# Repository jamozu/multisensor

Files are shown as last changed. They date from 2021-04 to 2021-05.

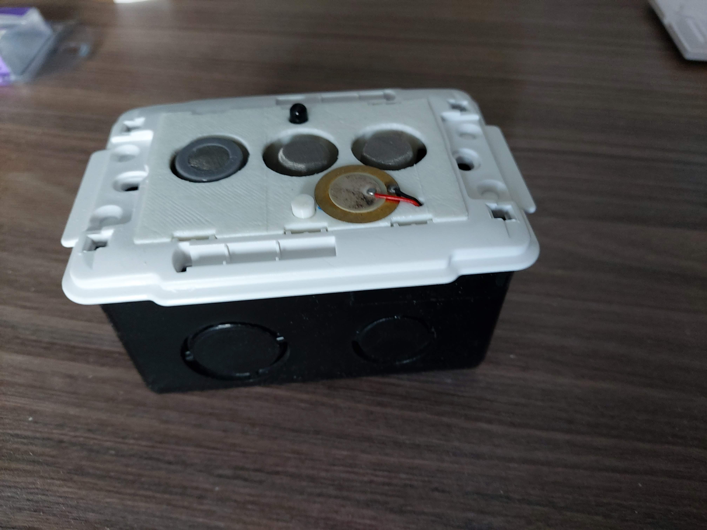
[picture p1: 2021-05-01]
pics/Pic_AQS_Assembled.jpg

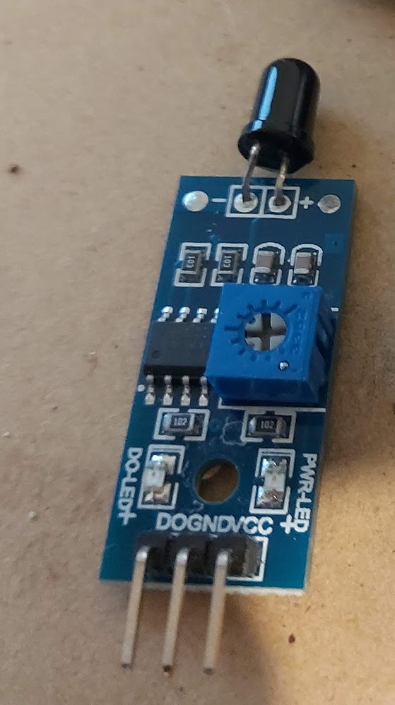
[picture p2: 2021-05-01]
pics/Pic_AQS_Flame.jpg

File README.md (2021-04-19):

# Multi-Sensor
This project consists of a module that manages different sensors for home use. The idea is to be able to mix and match different sensors, according to the requirements of each area of the house, using a single PCB design and a configurable sketch, making it easier to setup and maintain a sensor network.

The sensor module is based on the MySensors library using an Arduino® Mini Pro, which has a good number of interface pins, it has a small footprint and is suited for running on batteries, with the NRF24L01 radio module for wireless communication.

For a full description check the Doc Multi_Sensor.pdf (https://github.com/jamozu/multisensor/blob/main/Multi_Sensor.pdf).

Details on the PCB: https://oshwlab.com/jamozu/multi_project_copy_copy_copy_copy_copy_copy

# License
This project is licensed under the CERN-OHL-P v2

# Special Thanks to
MySensors Team, by creating a great and inspiring platform for all DIYers and IoT enthusiasts. (http://www.mysensors.org)
Damian and Gnd_To_Vcc, for their tips on using PIR sensors with 3.3 V (https://screenzone.eu/modify-hc-sr501-pir-sensor-to-work-with-3-3v/), (https://gndtovcc.home.blog/2020/04/23/modifying-cheap-pir-motion-sensor-to-work-at-3-3v/)
system, for an excellent template for writing values to EEPROM (https://forum.arduino.cc/t/writing-float-values-to-eeprom/41607/3)
hek, who has a very complete example of the use of air quality sensors. (https://www.mysensors.org/build/gas)
To all the DIYers out there who are enriching these IoT development platforms, making it easier for new enthusiasts.

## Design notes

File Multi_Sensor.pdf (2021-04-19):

## MULTI-SENSOR

This project consists of a module that manages different sensors for home use. The idea is to be able to mix and match different sensors, according to the requirements of each area of the house, using a single PCB design and a configurable sketch, making it easier to setup and maintain a sensor network.

## Description

The sensor module is based on the MySensors library using an Arduino® Mini Pro, which has a good number of interface pins, it has a small footprint and is suited for running on batteries.
The radio module for wireless communication is the NRF24L01.
It supports the following sensors:
- Motion Sensor.
- 1 – 3 Door / Window sensors.
- Temperature and humidity sensor.
- Flame sensor.
- Light sensor.
- LUX Sensor (I2C).
- Smoke sensor.
- Gas sensor.
- CO sensor.
- 1 – 3 Moisture sensors.
- 1 – 3 Leak detectors.

It also includes the features:
- Battery operation or battery backup
- Audible Alarm
- Reset / Test / Calibrate button

## Hardware

The module is based on the Arduino® Mini Pro and the NRF24L01 radio, using readily available sensor boards, connected through a PCB.
The sensor module can be powered using a small power supply, through batteries, or a combination of a power supply and rechargeable battery for backup.

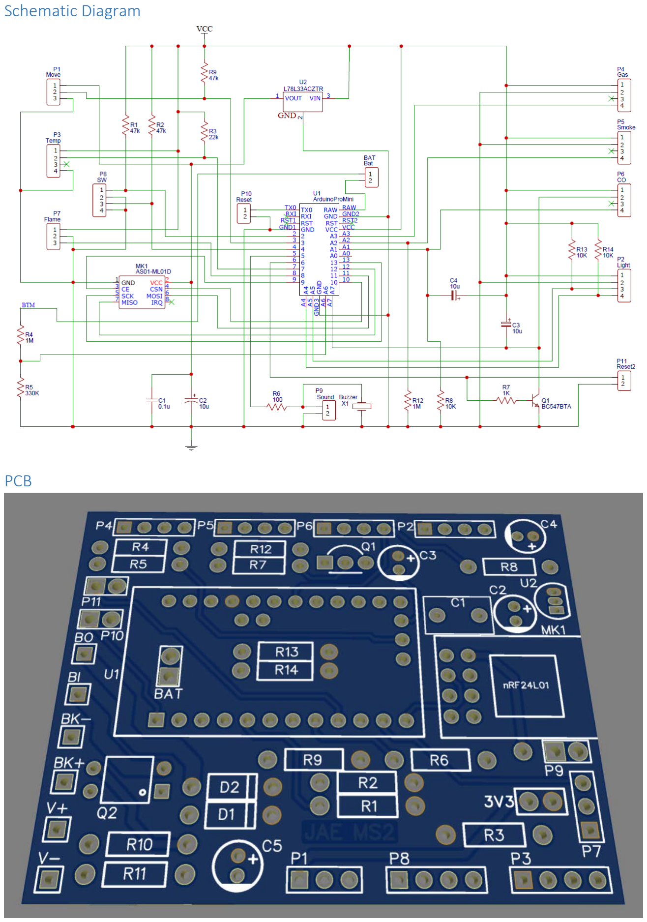
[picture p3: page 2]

Schematic Diagram

PCB

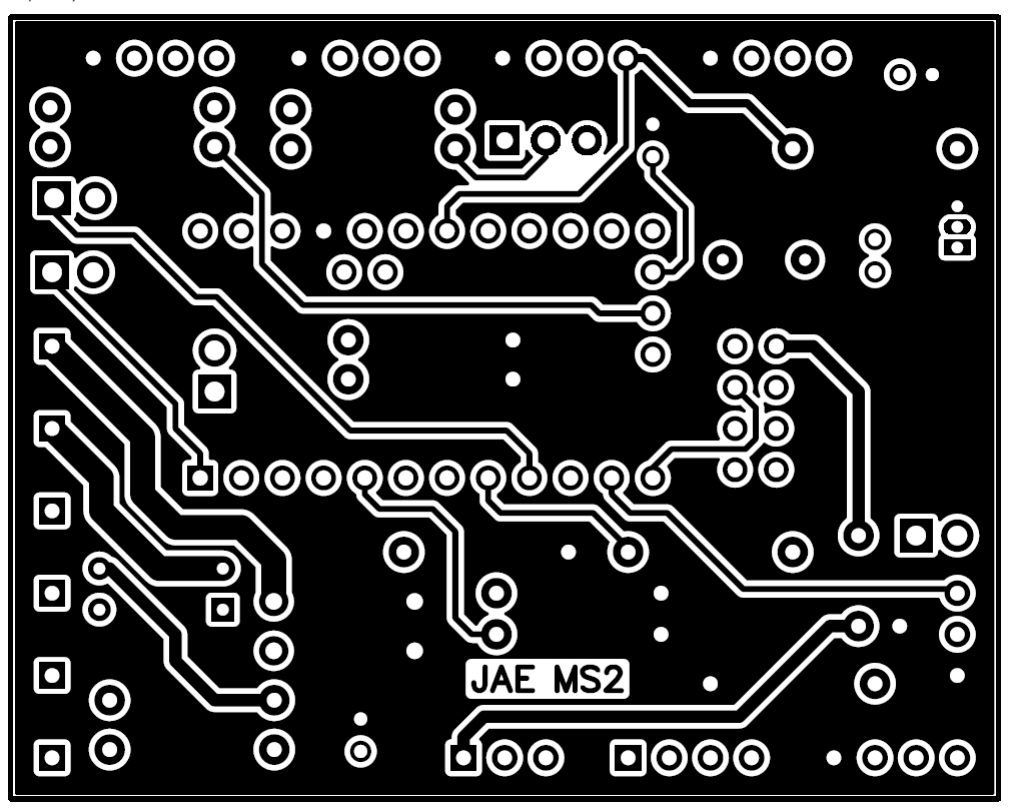
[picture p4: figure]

Top Layer

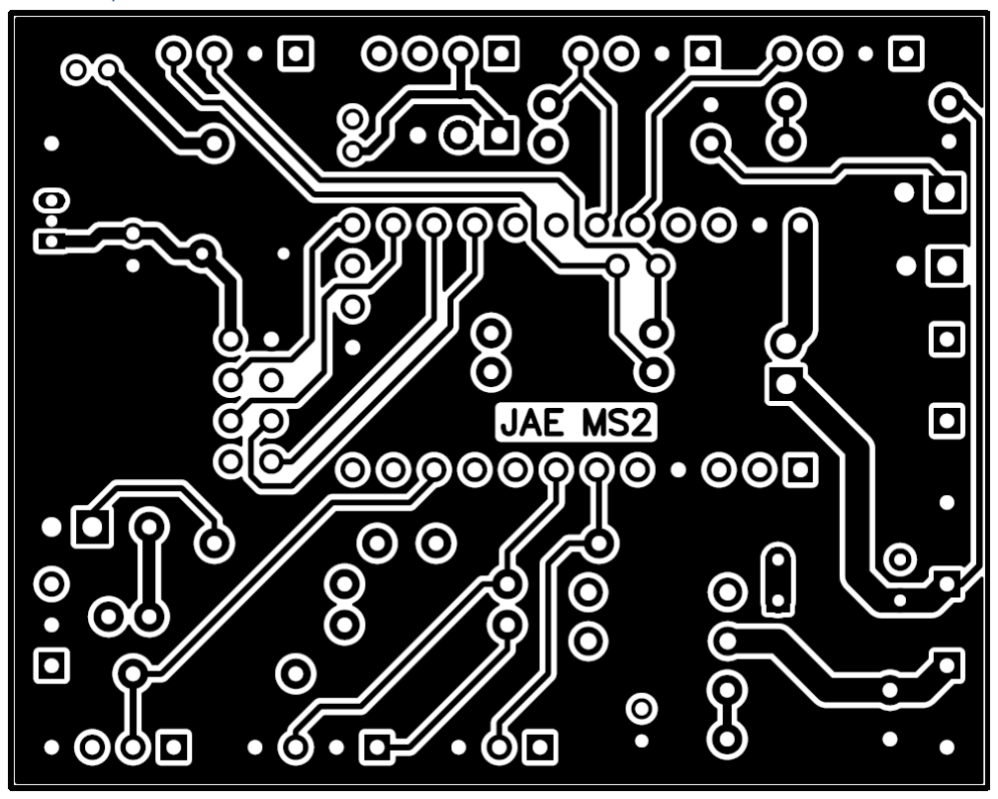
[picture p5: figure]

Bottom Layer

Component Silk Mask

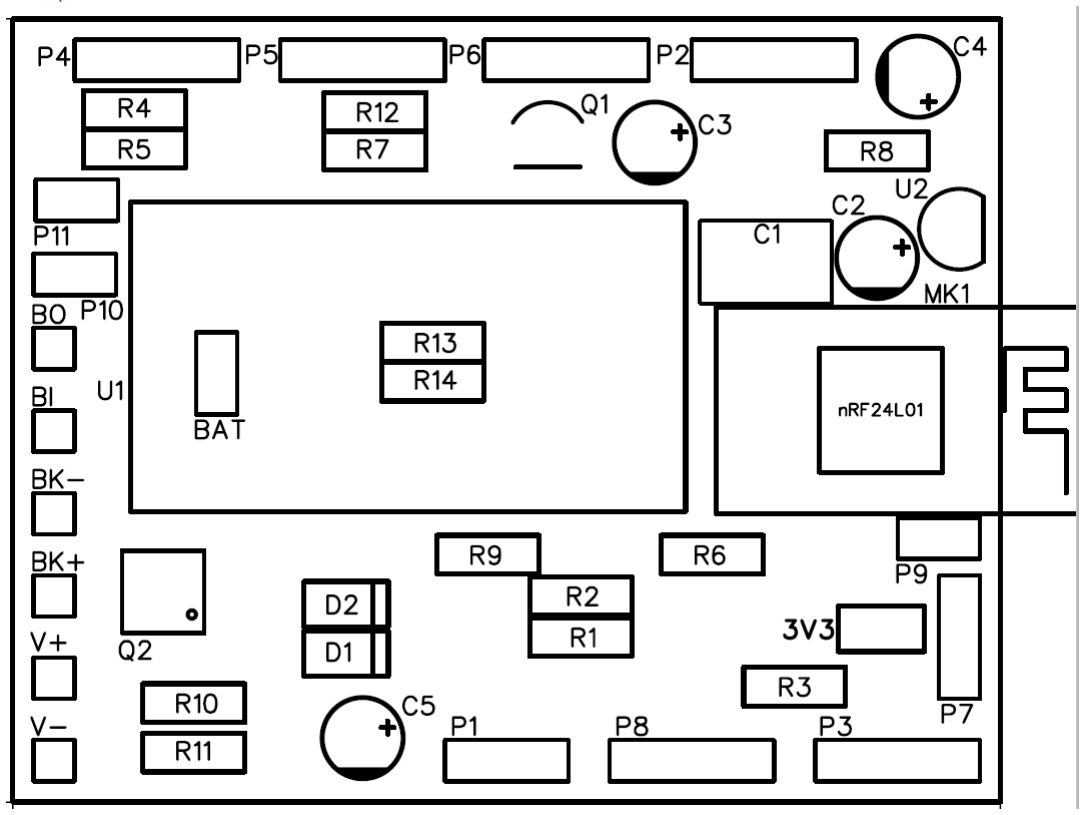
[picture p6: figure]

Microcontroller
The module can be configured with a 5V or 3.3V Arduino Pro Mini microcontroller module.
In the case of battery operation, it is recommended to use the 3.3V microcontroller. In this case, all sensors must be rated to operate at 3.3V.
In the case of a 5V microcontroller you can use 5V and 3.3V sensors in combination.
The NRF24L01 radio module requires 3.3V, so a regulator (U2) for the radio (and the motion sensor) is included in the circuit, in case of using a 5V microcontroller.
If the controller is 3.3V, the U2 regulator is not required, but it is necessary to put a jumper between terminals 1 and 3 of U2.

Sensors
Some of the sensors use the same pins in the microcontroller, so a combination of sensors can be chosen according to the following table:
Arduino Pins | Sensors | Features | Sleep
1 | | | | Button | N/A
2 | Door 1 | | | Button
3 | Door 2 | PIR Motion | | Button

4 | Door 3 | Optional
5 | | | | Alarm
7 | Temp. / Hum.
8 | Flame
6, A1, A7 | MQ-7 | Moist 3 | Leak 3 | Button | Optional
A2 | MQ-2 | Moist 2 | Leak 2
A3 | MQ-5 | Moist 1
A4, A5 | Light | Lux
A6 | | | | Battery monitor

The sensors that require it, have been configured with external Pull Up resistors to improve energy consumption and to be able to operate with batteries.
Sensor | VCC | Reference
PIR Motion Sensor | 3.3V, 5V | https://www.adafruit.com/product/189
Door Sensor | 3.3V, 5V | https://www.sparkfun.com/products/8642
| 3.3V, 5V | https://www.sparkfun.com/products/13247
| 3.3V, 5V | https://www.sparkfun.com/products/13014
Temp / Humidity sensor | 3.3V, 5V | https://learn.adafruit.com/dht
Light Sensor | 5V | https://www.makerfabs.com/light-sensor-module.html
| 3.3V, 5V | https://www.adafruit.com/product/2748
| 3.3V, 5V | http://arduinolearning.com/code/arduino-lx1972-light-sensor-example.php (http://arduinolearning.com/code/arduino-lx1972-light-sensor-example.php)
LUX Sensor | 3.3V, 5V | https://www.adafruit.com/product/4162
| 3.3V, 5V | https://www.adafruit.com/product/439
| 3.3V, 5V | https://www.adafruit.com/product/4681
Flame Sensor | 3.3V, 5V | https://www.pcboard.ca/flame-sensor-module
Smoke Sensor | 5V | https://www.smart-prototyping.com/MQ2-gas-sensors-module.html (https://www.smart-prototyping.com/MQ2-gas-sensors-module.html)
Gas Sensor | 5V | https://www.smart-prototyping.com/MQ-5-Methane-Gas-Sensor-Module.html?search=mq-5 (https://www.smart-prototyping.com/MQ-5-Methane-Gas-Sensor-Module.html?search=mq-5)
CO Sensor | 5V | https://www.waveshare.com/mq-7-gas-sensor.htm
Moisture sensor | 3.3V, 5V | https://www.seeedstudio.com/Grove-Capacitive-Moisture-Sensor-Corrosion-Resistant.html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 (https://www.seeedstudio.com/Grove-Capacitive-Moisture-Sensor-Corrosion-Resistant.html)
| 3.3V, 5V | https://www.seeedstudio.com/Grove-Moisture-Sensor.html
Leak Sensor | 3.3V, 5V | https://www.aartech.ca/vip1000-h2o/flair-waterguard-water-detector-5-24vdc-white.html (https://www.aartech.ca/vip1000-h2o/flair-waterguard-water-detector-5-24vdc-white.html)

Wiring
a) Motion sensor

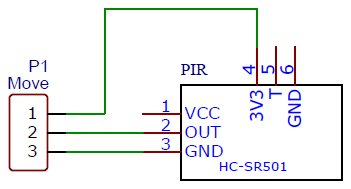
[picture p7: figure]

Install 47 KOhms resistor R9.
The motion sensor is connected to the 3.3V source, which is more efficient in power consumption. Consider the next articles for details on how to connect the PIR sensor: https://screenzone.eu/modify-hc-sr501-pir-sensor-to-work-with-3-3v/https://gndtovcc.home.blog/2020/04/23/modifying-cheap-pir-motion-sensor-to-work-at-3-3v/
b) Door sensors 1 and 3

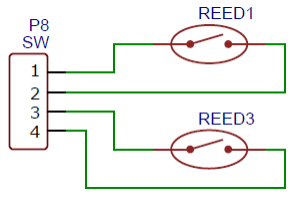
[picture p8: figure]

Install 47 KOhms resistors R1 (Door 1) and R2 (Door 2).

c) Door sensor 2

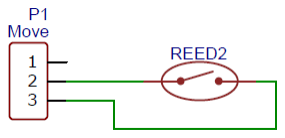
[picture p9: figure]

Install 47 KOhms resistor R9.

d) Temperature / Humidity sensor

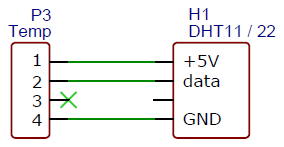
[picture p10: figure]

Install 22 KOhms resistor R3.

e) Light sensor

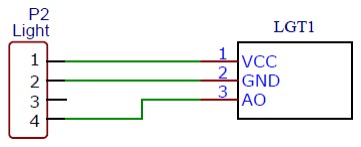
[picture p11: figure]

f) LUX Sensor
This sensor connects using two data pins with the I2C protocol. Any other I2C compatible sensor can be used instead or in parallel, but the sketch must be modified and the corresponding libraries installed.

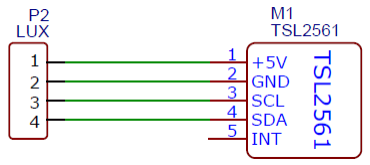
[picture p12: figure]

Install 10 KOhms resistors R13 and R14.

g) Flame sensor

Air Quality Sensors
The module supports 3 air quality sensors. MQ-2, MQ-5 and MQ-7. It is possible to replace the MQ-2 and MQ-5 with others similar sensors to detect specific gases, but the curves for the calculation of PPMs must be adjusted in the sketch. These MQ sensors have different sensitivities to different gases, however it is not possible to differentiate between one specific gas, for this reason the module has been equipped with a sensor for general air quality detection (MQ-2) and other more specific ones in order to have an accurate reading of the type of gas present, if required.
These sensors can consume up to 900mA, so it is not suitable for battery operation, so it is recommended to have a power supply with backup batteries, especially if using more than one sensor simultaneously.
For a simple, general use sensor and triggering an alarm, a single MQ-2 sensor is enough. If a more accurate reading of flammable gases is required, the MQ-5 can be used and MQ-7 can be used to detect Carbon Monoxide more accurately. The MQ-2 is a general-purpose sensor that can detect:
- Smoke
- Liquefied Petroleum Gas (LPG)
- Natural Gas (CH4)
- Carbon Monoxide (CO)
The MQ-5 is sensor focused on flammable gases and can detect:
- Liquefied Petroleum Gas (LPG)
- Natural Gas (CH4)
The MQ-7 sensor is specific for Carbon Monoxide. This sensor requires the application of two voltage levels alternately, so it requires constant operation of the microprocessor, so if this sensor is activated, the sleep mode is deactivated. The air quality sensors can be used to trigger an alarm or exclusively for monitoring.
When any of the air quality sensors is enabled in the module, the calibration button is automatically enabled. See below on the BUTTON and INTERRUPTIONS sections for more details.
If the alarm feature is enabled, it will be trigger if certain levels are reached in the monitored gases. The button is also used to reset / test the alarm.
h) Smoke sensor

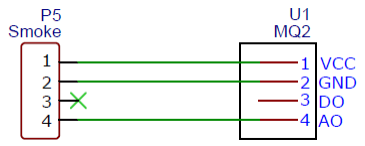
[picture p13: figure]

i) Gas sensor

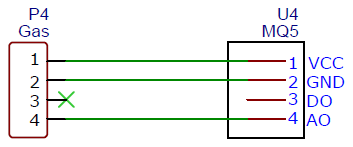
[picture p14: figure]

j) Carbon Monoxide sensor

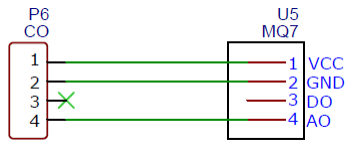
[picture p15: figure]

Install 1 KOhms resistor R7, 10 KOhms resistor R8, 10uF tantalum capacitors C3 and C4, and transistor Q1 (BC547B).

Moisture / Leak Sensors
Moisture sensors are used to measure humidity in media such as soil, but can also be used as water leak detectors, setting a humidity threshold.
The type of sensors supported are:
- https://www.seeedstudio.com/Grove-Capacitive-Moisture-Sensor-Corrosion-Resistant.html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 (https://www.seeedstudio.com/Grove-Capacitive-Moisture-Sensor-Corrosion-Resistant.html)
- https://www.seeedstudio.com/Grove-Moisture-Sensor.html
For the humidity in the soil it is recommended to use the capacitive type, since they are more durable and do not release harmful residues that can affect the chemistry of the soil.
There are other types of sensors that are used specifically to detect leaks:
- https://www.aartech.ca/vip1000-h2o/flair-waterguard-water-detector-5-24vdc-white.html
These sensors require a Pull Up resistor. The module supports two of these sensors in positions 2 and 3. Moisture sensors use the same analog inputs as gas sensors.
- Moisture 1 uses the same Analog Pin as the MQ-5 Air quality sensor.
- Moisture 2 uses the same Analog Pin as the MQ-2 Air quality sensor.
- Moisture 3 uses the same Analog Pin as the MQ-7 Air quality sensor.
k) Moisture sensors 1 – 3

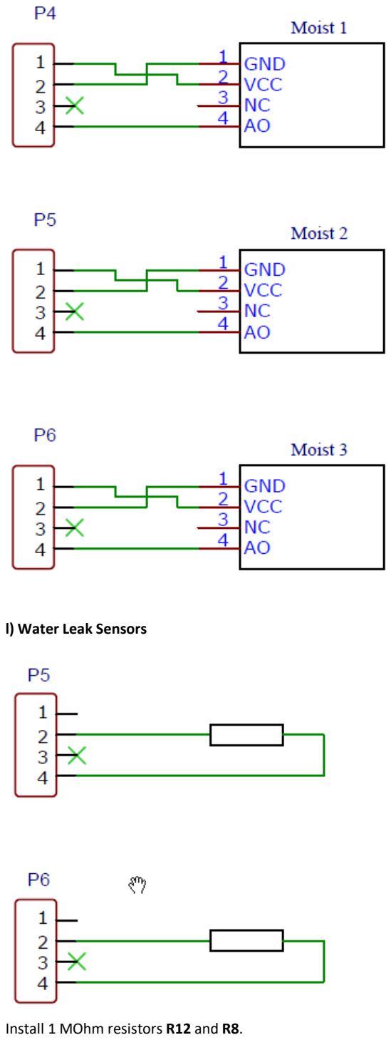
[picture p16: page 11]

l) Water Leak Sensors

Install 1 MOhm resistors R12 and R8.

Features

Alarm
The alarm is based on a simple piezoelectric transducer, which can produce sounds at an acceptable volume.

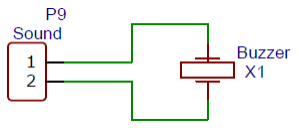
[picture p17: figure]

Install 100 Ohm resistors R6.
Alarm Triggers
The alarm can be triggered by various gas measurements or moisture sensors.
- Flame | On/Off (The threshold is calibrated in the sensor module)
- Smoke | 300ppm
- LPG | 300ppm
- Natural gas 300ppm
- CO 40ppm
- Leak/Flood 1 10%
- Leak/Flood 2 10%
- Leak/Flood 3 10%

Button
The button is used to Reset and Test the alarm, as well as to Calibrate the Air Quality sensors.
- Short press; Less than 3 seconds. Resets the alarm (it will stay off for at least 30 seconds; see
ALARM_RETRIGGER in the sketch).
- Long press; 3-5 seconds. Starts an alarm test for 10 seconds (See ALARM_TEST in the sketch).
- Very long press; Longer than 6 seconds. Starts a calibration for the Air Quality sensors. The sensors need to be in clean air for the calibration to be effective.
The button can be installed on pins 2 (default) or 3, depending on the other sensors present. If the button is installed in these positions, an interruption is assigned to the button and the microcontroller can enter sleep mode.
If these pins are not available, it can be installed on pin 6 or on pin 1. In these cases the sleep cycle is suspended and for pin 1 the debugging for the serial port is deactivated.

Power
The module can be powered in several ways:
- Using a 5V power supply. I have used small USB chargers successfully.
- Using batteries. In this case I have tested 2 configurations.
- Using 2 1.5V cells and a voltage booster or buck converter
- Using 3 1.5V cells directly.
- Using a 5V power supply and a rechargeable LiPo cell for backup.
Power mode | VCC | Arduino 5V | Arduino 3.3V | Jumpers
5V Power Supply | 5V | X | | D1
5V Power Supply + Battery Backup | 5V | X
3V (2 AA batteries) | 3.3V | | X | D1, U2 (Pins 1 and 3)
4.5V (2 AA batteries) | 3.3V | | X | BAT, U2 (Pins 1 and 3)

Power Supply

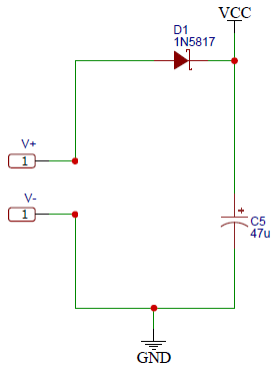
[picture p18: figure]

The use of diode D1 is optional and can be replaced by a jumper.

2 Cells

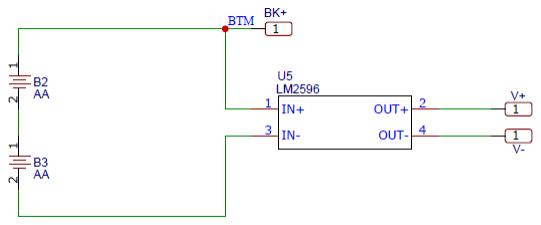
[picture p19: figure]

Set a jumper cable in the position of D1 and other between pins 1 and 3 of U2 (3.3V Regulator). The regulator U2 is not required.

3 Cells

Set a jumper cable in the position BAT and other between pins 1 and 3 of U2 (3.3V Regulator). The regulator U2 is not required.

Power Supply with Backup

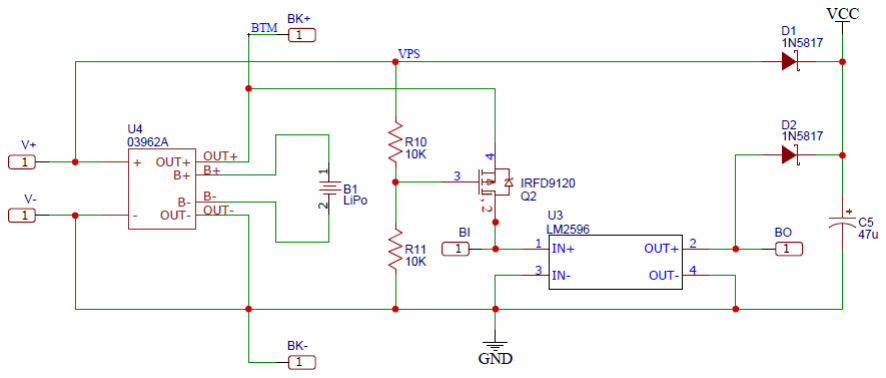
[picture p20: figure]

Interruptions
The Arduino Mini Pro has 2 hardware interruptions that can wake up the module from sleep. This module supports 4 elements that require these interruptions:
- Motion sensor (IRQ3)
- Door sensor 1 (IRQ2)

- Door sensor 2 (IRQ3)
- Reset / Test / Calibrate button (IRQ2)
The button is required to operate the alarm and is also used to calibrate the air quality sensors.
The Door Sensor 1 and Button share the same interrupt by default, so you have to select between these two features, also the Motion Sensor and the Door Sensor 2 use the same pin, so you have to configure one or the other.

Sleep Cycle
During normal operation, the microcontroller reads the status of all sensors, then goes into a sleep cycle for one minute, to minimize power consumption. The controller can wake up after the time has elapsed or if activity is detected in the sensors that have hardware interruptions.
The sleep cycle can be disabled temporarily if:
- Alarm is On
- The button is pressed
- MQ-7 sensor is enabled
- Wait for child initial presentation to occur And it is permanently disabled if:
- The button is set in pins 1 or 6
- MQ-7 sensor is permanently enabled
- The module is configured as a repeater for the MySensors network

Bill of material

Name | Designator | Quant ity | Description | Link
nRF24L01+ | MK1 | 1 | Radio Module | https://www.aliexpress.com/item/10000372208801.html
ArduinoPro Mini | U1 | 1 | Microcontroller | https://www.arduino.cc/en/pmwiki.php?n=Main/ArduinoBoardProMini
L78L33ACZT R | U2 | 1 | 3.3 V Linear regulator | https://www.digikey.com/en/products/detail/stmicroelectronics/L78L33ACZTR/1038305?s=N4IgTCBcDaIDIHY AccDMqCCBhAWgFQCUQBdAXyA (https://www.digikey.com/en/products/detail/stmicroelectronics/L78L33ACZTR/1038305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)
03962A | U4 | 1 | LiPo Battery charger | https://www.addicore.com/TP4056-Charger-and-Protection-Module-p/ad310.htm
LM2596 | U3,U5 | 1 | DC-DC Boost Converter Step-Up. NOTE: Make sure to get a Step-Up converter and not a Step-Down. | https://www.itead.cc/power/dc-dc.html
0.1u | C1 | 1 | Ceramic Capacitor | https://www.digikey.com/en/products/detail/kemet/C326C104K3G5TA7301/6671327
10u | C2,C3,C4 | 3 | Electrolytic Capacitor | https://www.digikey.com/en/products/detail/panasonic-electronic-components/ECA-1EM100I/2688677
47u | C5 | 1 | Electrolytic Capacitor | https://www.mouser.com/ProductDetail/Nichicon/UVR1E470MDD1TA?qs=nd5JBRjZIXgOh2LQ2cd6pg%3D%3 D (https://www.mouser.com/ProductDetail/Nichicon/UVR1E470MDD1TA?qs=nd5JBRjZIXgOh2LQ2cd6pg%3D%3D)
1N5817 | D1,D2 | 2 | Schottky Rectifier | https://www.mouser.com/ProductDetail/ON-Semiconductor-Fairchild/1N5817?qs=Ro3gc6G1sTm8wr1Du93jFw%3D%3D (https://www.mouser.com/ProductDetail/ON-Semiconductor-Fairchild/1N5817?qs=Ro3gc6G1sTm8wr1Du93jFw%3D%3D)
BC547BTA | Q1 | 1 | NPN Transistor | https://www.mouser.com/ProductDetail/ON-Semiconductor-Fairchild/BC547BTA?qs=TABiY4F6Vcf01oKZdNLa0w%3D%3D (https://www.mouser.com/ProductDetail/ON-Semiconductor-Fairchild/BC547BTA?qs=TABiY4F6Vcf01oKZdNLa0w%3D%3D)
IRFD9120 | Q2 | 1 | MOSFET | https://www.mouser.com/Search/Refine?Keyword=IRFD9120
22k | R3 | 1 | Resistor 1/4W | https://www.mouser.com/ProductDetail/TE-Connectivity-Holsworthy/CBT25J22K?qs=VHcS2MTj4gYx622ynmvRcg%3D%3D (https://www.mouser.com/ProductDetail/TE-Connectivity-Holsworthy/CBT25J22K?qs=VHcS2MTj4gYx622ynmvRcg%3D%3D)
1M | R4, R12, (R8) | 2 | Resistor 1/4W | https://www.mouser.com/ProductDetail/TE-Connectivity-Holsworthy/CBT25K1M0?qs=vLWxofP3U2yRkXFSovy3WQ%3D%3D (https://www.mouser.com/ProductDetail/TE-Connectivity-Holsworthy/CBT25K1M0?qs=vLWxofP3U2yRkXFSovy3WQ%3D%3D)
330K | R5 | 1 | Resistor 1/4W | https://www.mouser.com/ProductDetail/Kamaya/RC1-4334KTB?qs=F5EMLAvA7IBvU3lvZkWOPQ%3D%3D
100 Ohm | R6 | 1 | Resistor 1/4W | https://www.mouser.com/ProductDetail/TE-Connectivity-Holsworthy/CBT25J100R?qs=VHcS2MTj4gan3wTTNkvgnA%3D%3D (https://www.mouser.com/ProductDetail/TE-Connectivity-Holsworthy/CBT25J100R?qs=VHcS2MTj4gan3wTTNkvgnA%3D%3D)

1K | R7 | 1 | Resistor 1/4W

https://www.mouser.com/ProductDetail/TE-Connectivity-Neohm/CBT25J1K0?qs=VHcS2MTj4gbgcyA0qV722Q%3D%3D (https://www.mouser.com/ProductDetail/TE-Connectivity-Neohm/CBT25J1K0?qs=VHcS2MTj4gbgcyA0qV722Q%3D%3D)
10K | (R8), R10, R11, R13, R14 | 5 | Resistor 1/4W | https://www.mouser.com/ProductDetail/TE-Connectivity-Holsworthy/CBT25J10K?qs=VHcS2MTj4gYWJg5s4QtMBw%3D%3D (https://www.mouser.com/ProductDetail/TE-Connectivity-Holsworthy/CBT25J10K?qs=VHcS2MTj4gYWJg5s4QtMBw%3D%3D)
47k | R1, R2, R9 | 3 | Resistor 1/4W | https://www.mouser.com/ProductDetail/TE-Connectivity-Neohm/CBT25J47K?qs=VHcS2MTj4gbIt9aO8l9ysw%3D%3D (https://www.mouser.com/ProductDetail/TE-Connectivity-Neohm/CBT25J47K?qs=VHcS2MTj4gbIt9aO8l9ysw%3D%3D)
Buzzer | X1 | 1 | Piezo Trasnducer | https://www.digikey.com/en/products/detail/murata-electronics/7BB-20-6L0/4358152
LiPo | B1 | 1 | LiPo cell | https://www.digikey.com/en/products/detail/mikroelektronika/MIKROE-4471/13679389
AA Battery | B2,B3,B4,B5, B6 | 2 - 3 | AA Rechargeable Battery | https://www.mouser.com/ProductDetail/Panasonic-Battery/HHR-70AAAB7?qs=1VjY50kO94REvXlpJrz3gA%3D%3D (https://www.mouser.com/ProductDetail/Panasonic-Battery/HHR-70AAAB7?qs=1VjY50kO94REvXlpJrz3gA%3D%3D)
BI | BI,BK+,BK-,BO,V+,V- | 1 | 2.54mm Header | https://www.mouser.com/ProductDetail/TE-Connectivity-AMP/5-826938-0?qs=xF5SkmKSM747%252BA1%2FGulWHw%3D%3D (https://www.mouser.com/ProductDetail/TE-Connectivity-AMP/5-826938-0?qs=xF5SkmKSM747%252BA1%2FGulWHw%3D%3D)
BK+ | P1, P2, P3, P4, P4, P5, P6, P7, P8, P9, P10, P11 | 1 | 2.54mm Header

Push Button
Dupont Cables

## Motion / Light / Temperature module

Below are the images of the module assembly with motion, temperature / humidity and light level sensors. The module is powered by 120V using a 5V USB charger and battery backup.

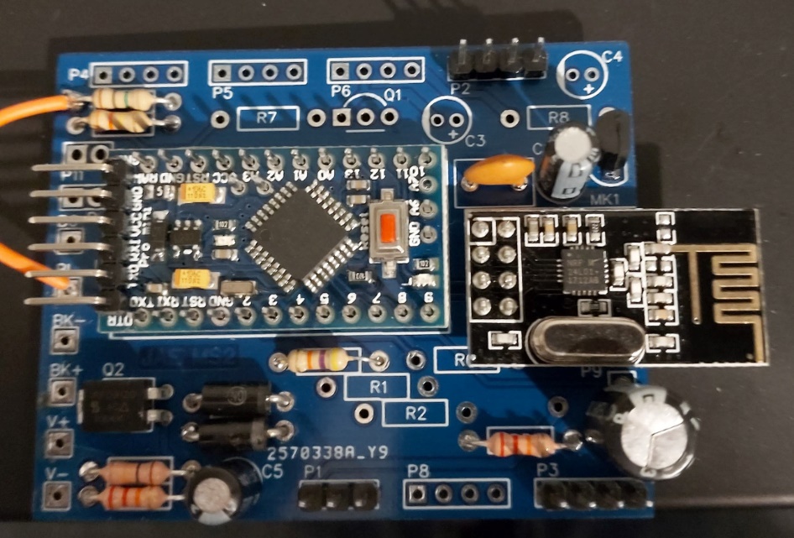
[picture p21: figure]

PCB Asselmbly

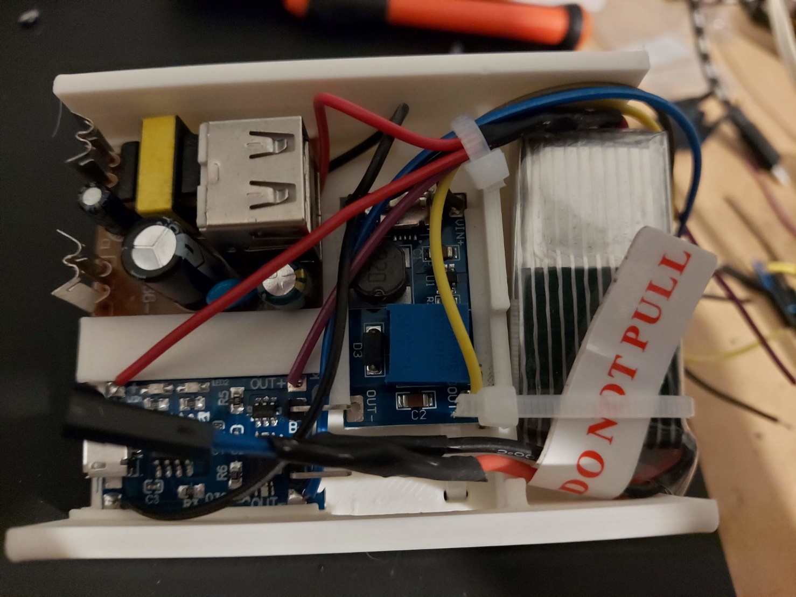
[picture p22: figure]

Power elements. USB Charger, Battery charger, Buck converter and LiPo battery.

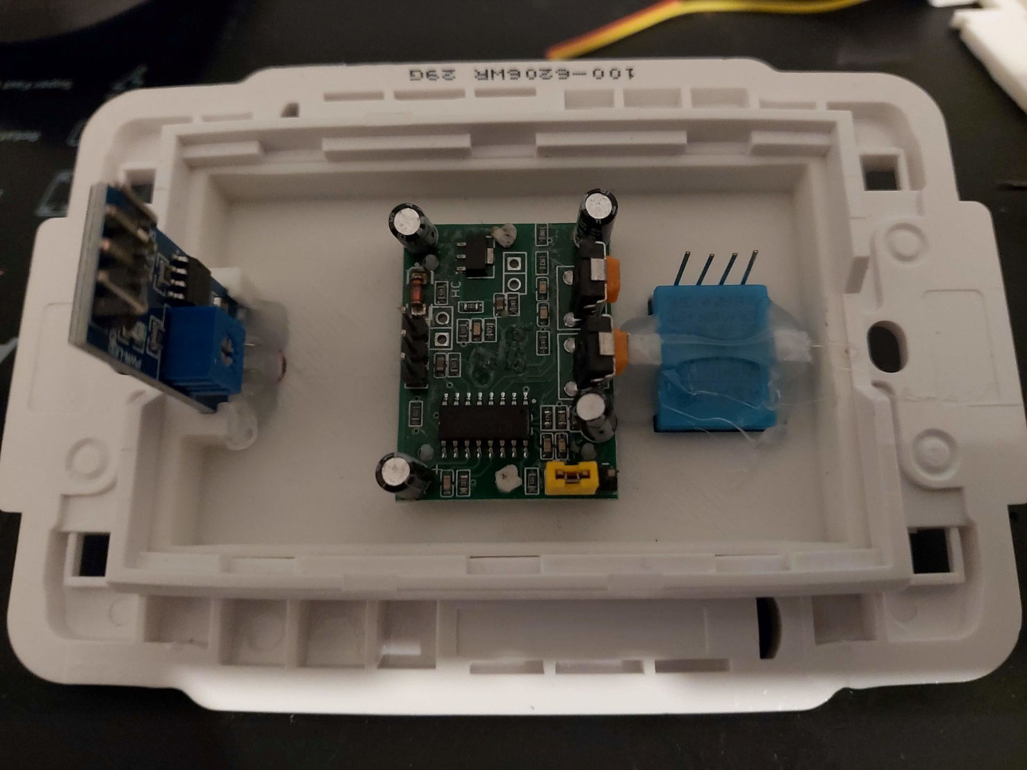
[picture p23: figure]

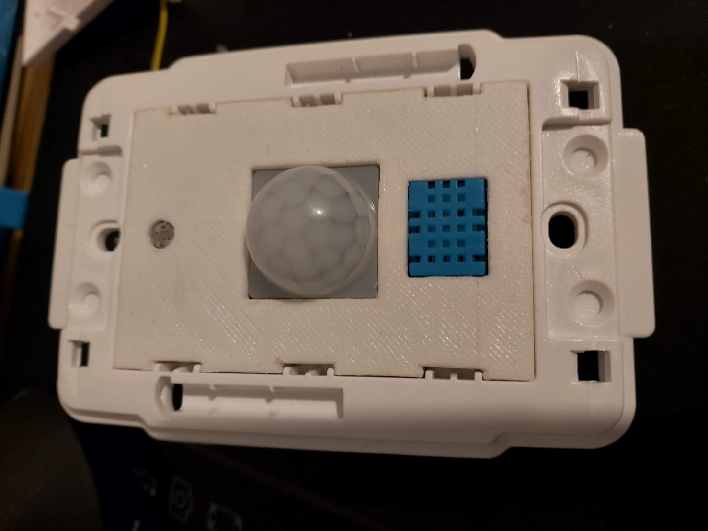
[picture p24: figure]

Left to right: Light, Motion and temperature sensors.

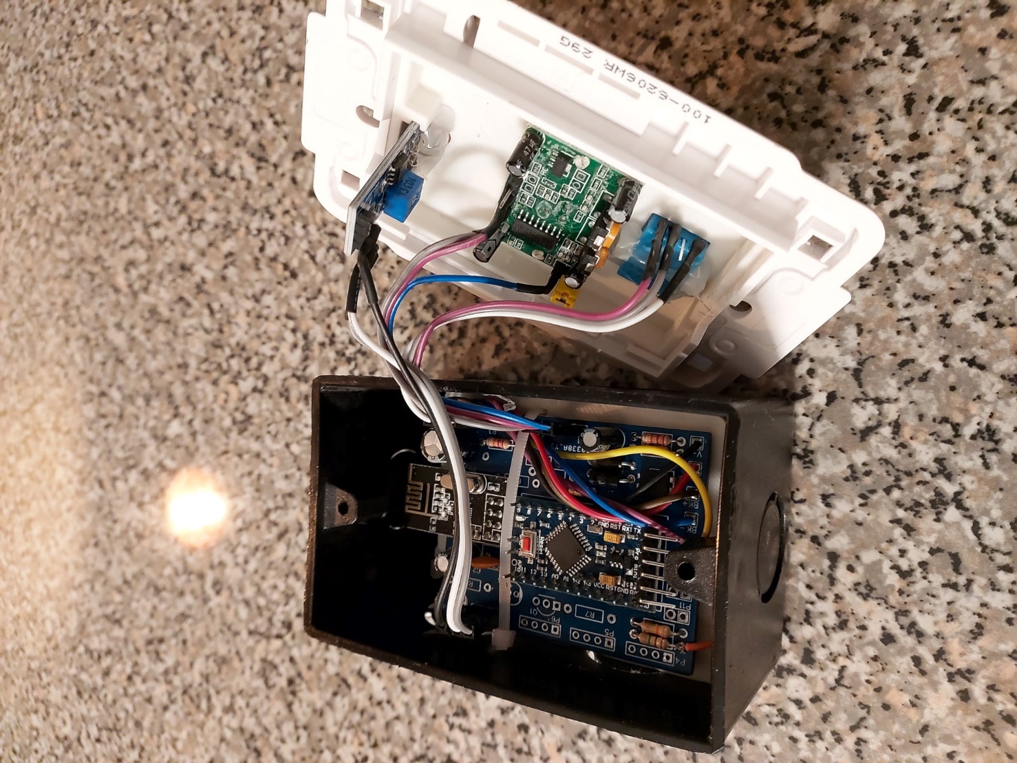
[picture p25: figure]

Full assembly.

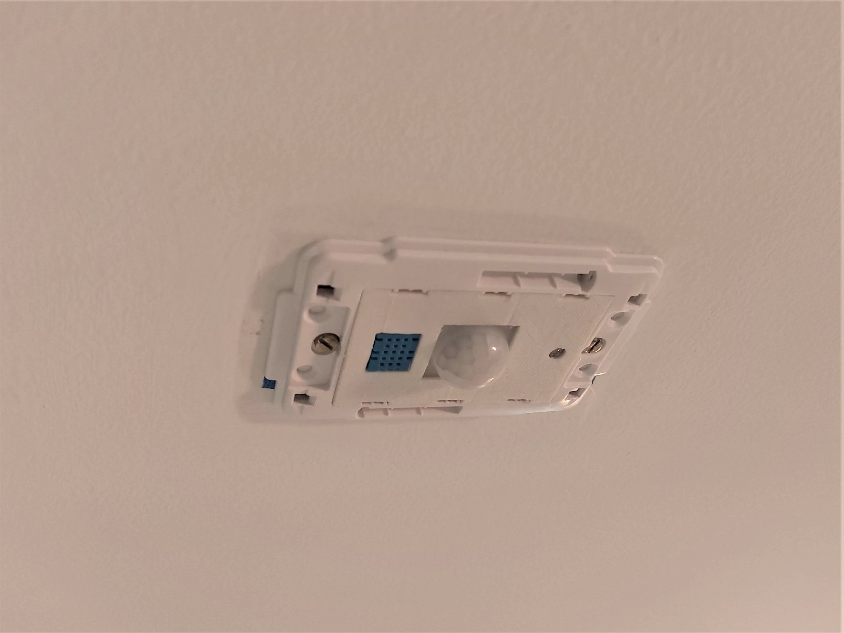
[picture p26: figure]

Module mounted on the ceiling drywall.

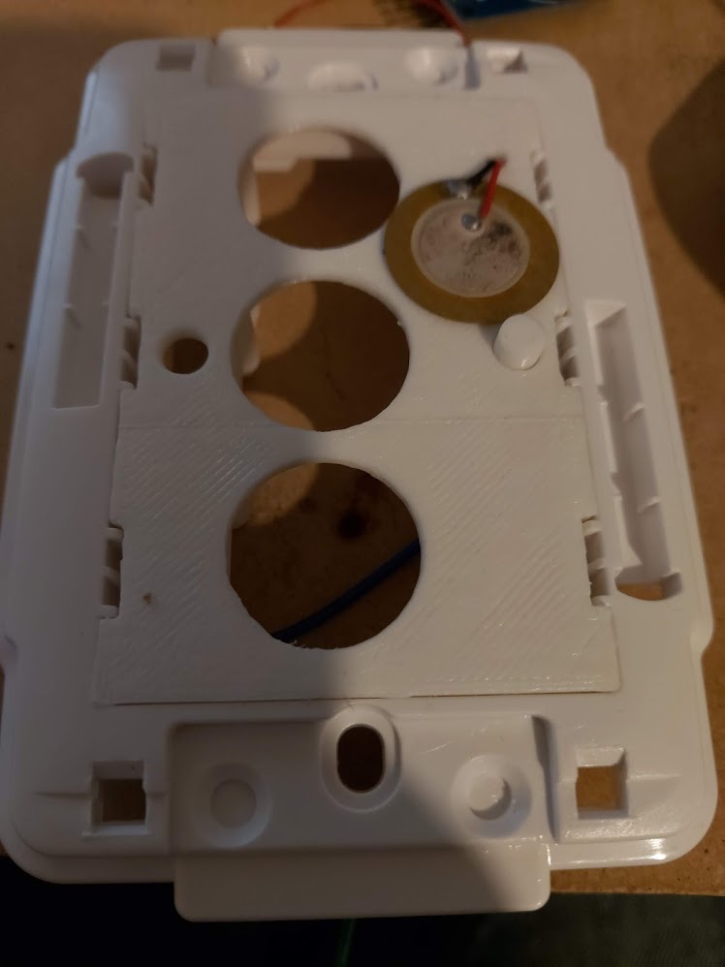
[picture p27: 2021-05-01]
pics/Pic_AQS_Base01.jpg

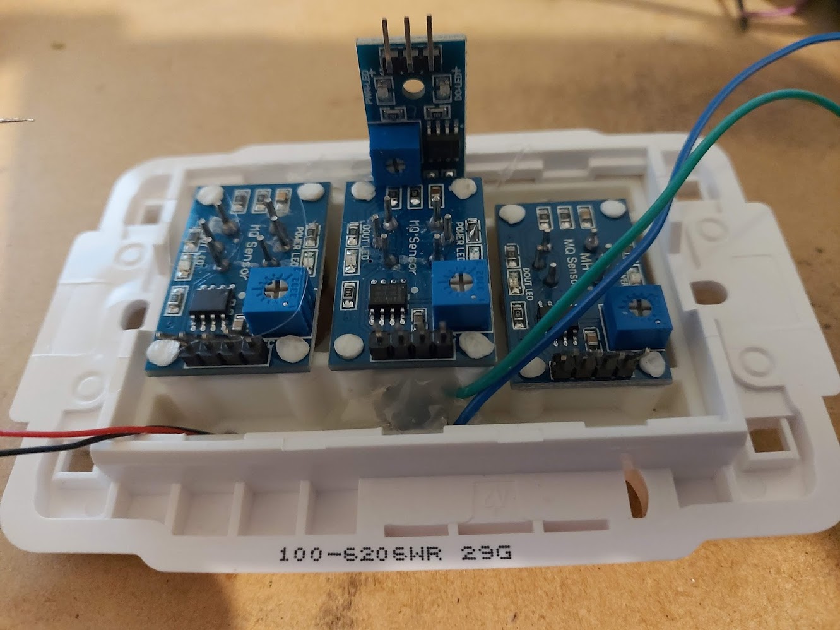
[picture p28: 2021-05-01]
pics/Pic_AQS_Mounted.jpg

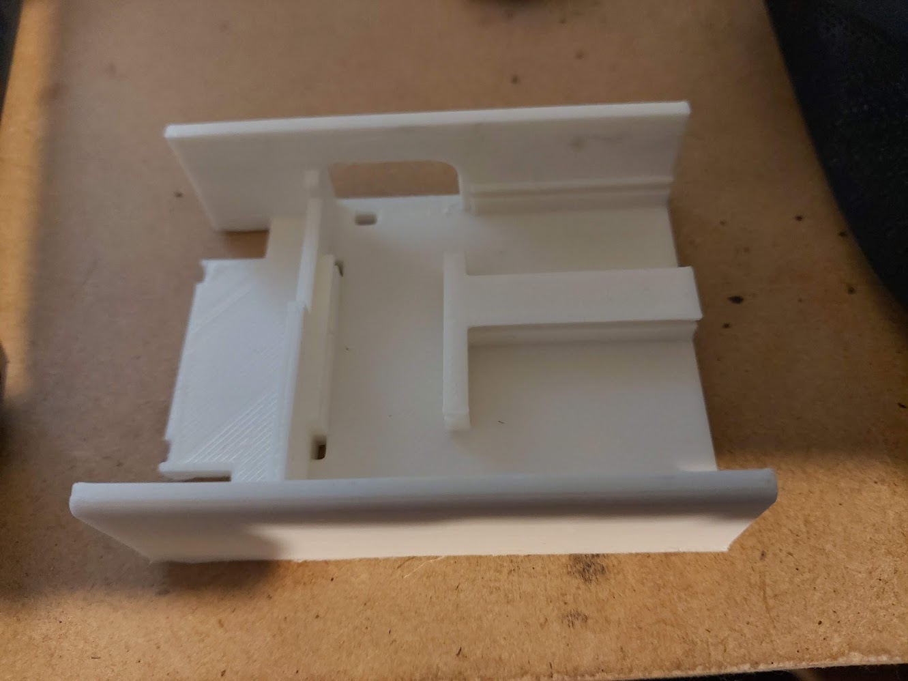
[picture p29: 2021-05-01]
pics/Pic_Module_Base.jpg

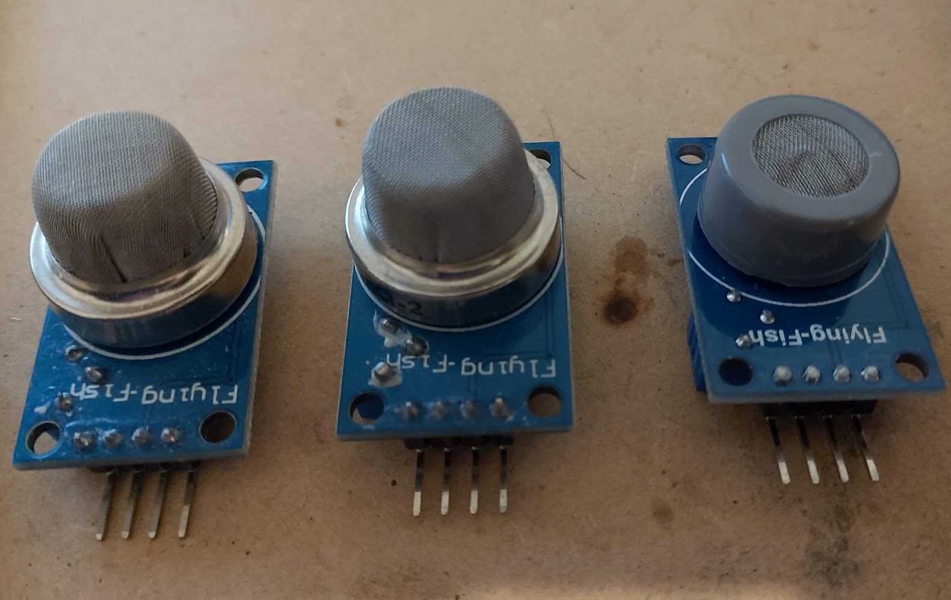
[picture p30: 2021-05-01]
pics/Pic_AQS_Sensors.jpg

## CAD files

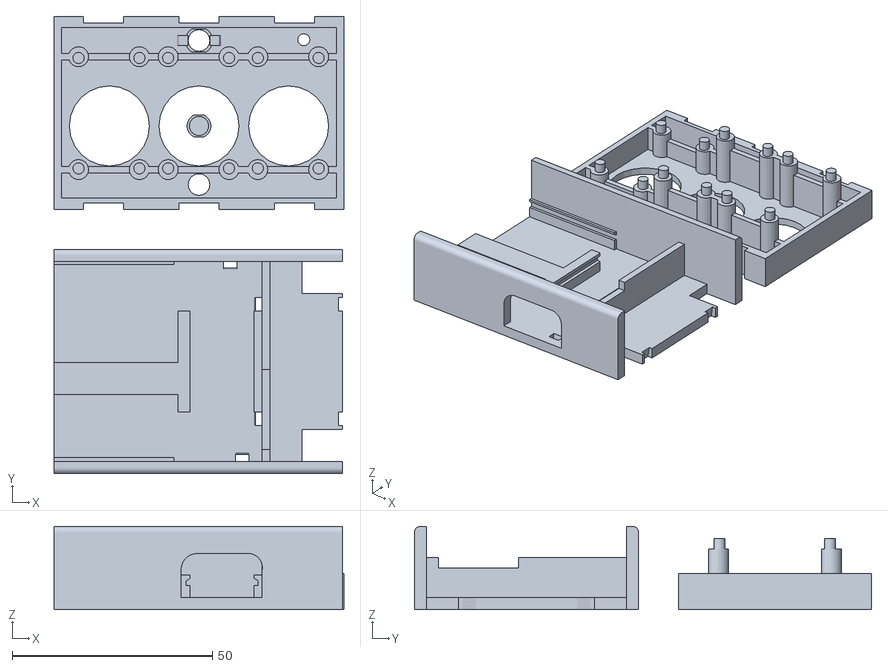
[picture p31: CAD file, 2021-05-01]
hardware/AQS_Mount.stl
72.4 x 114.2 x 20.8

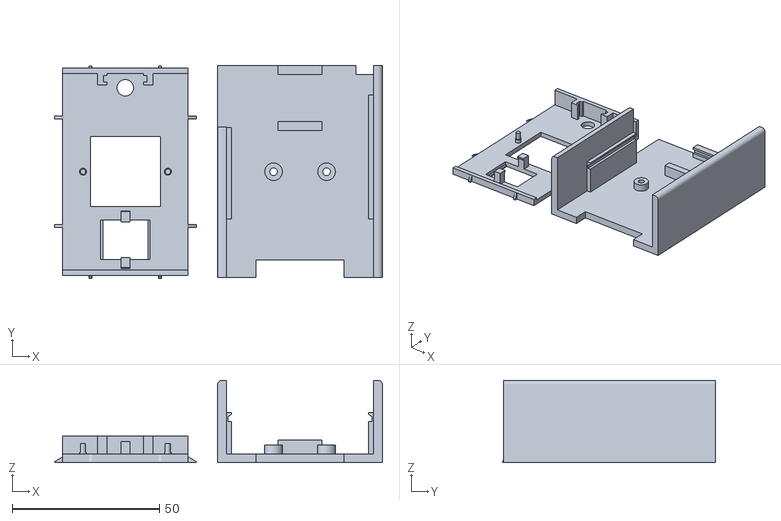
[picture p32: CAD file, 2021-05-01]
hardware/Motion_with_battery_Mount.stl
111.4 x 72.2 x 28.0

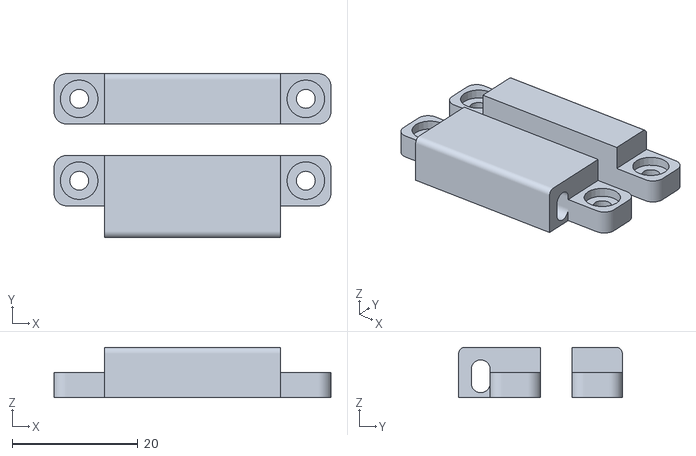
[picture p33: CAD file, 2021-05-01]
hardware/Door_Sensor_Housing.stl
44.0 x 26.0 x 8.00

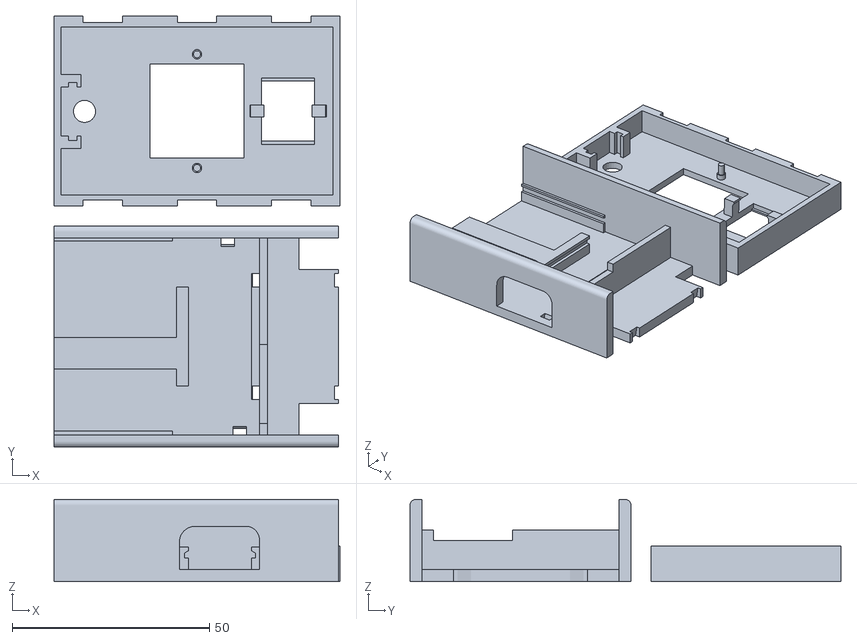
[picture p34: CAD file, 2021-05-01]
hardware/Motion_Temp_Mount.stl
72.4 x 109.2 x 20.8

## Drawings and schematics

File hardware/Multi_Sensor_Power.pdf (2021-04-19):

## GND

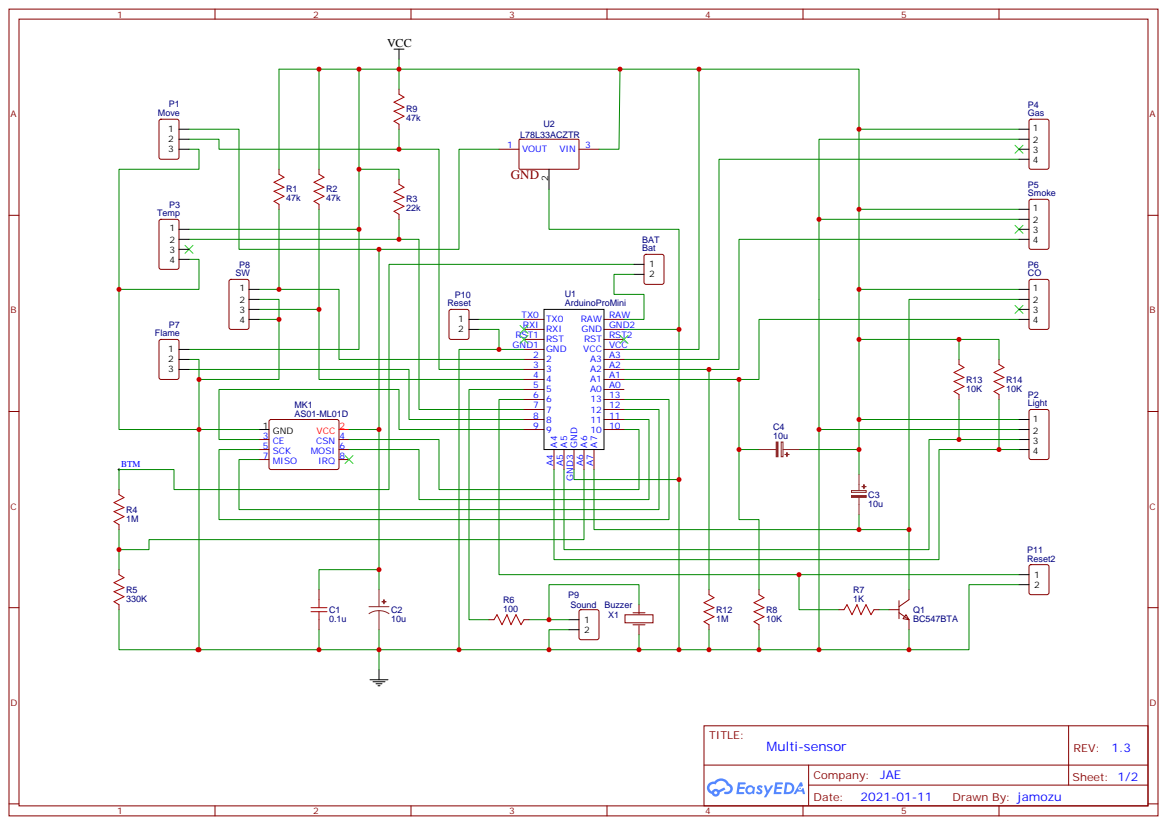
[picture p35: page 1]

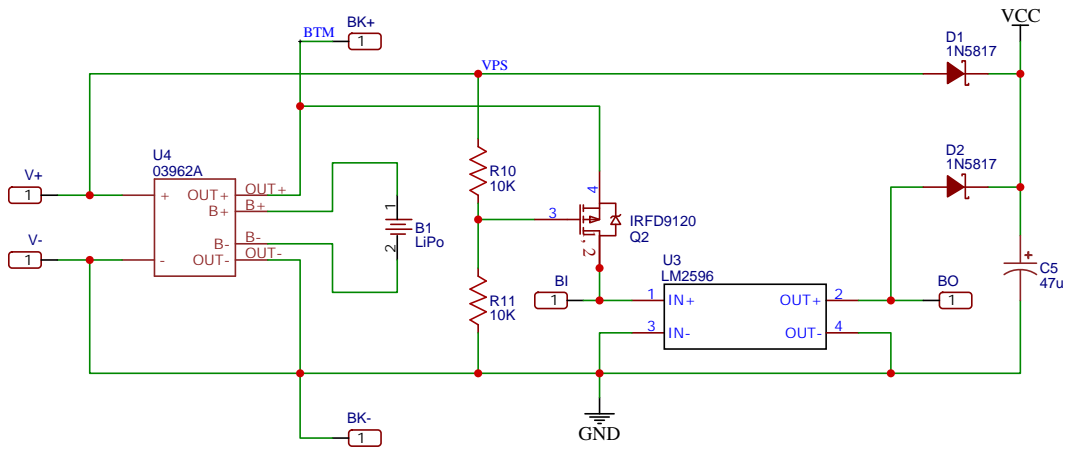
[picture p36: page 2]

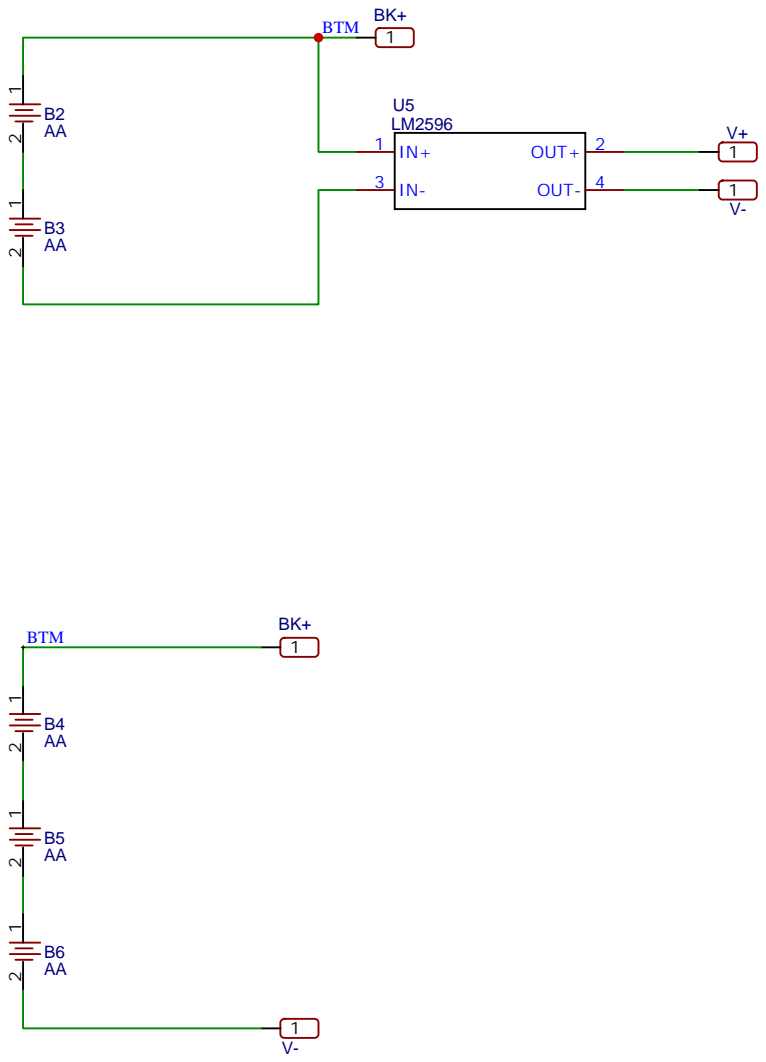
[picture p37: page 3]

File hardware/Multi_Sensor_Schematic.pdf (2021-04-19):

## GND

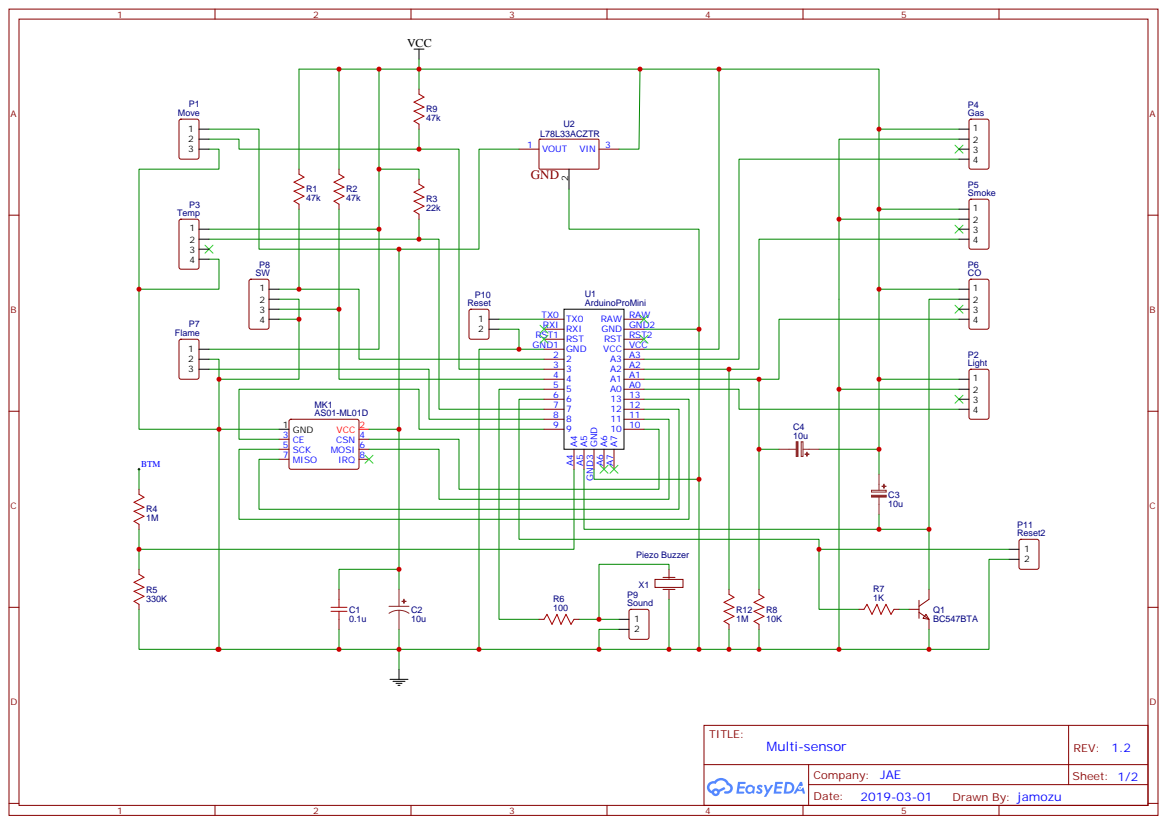
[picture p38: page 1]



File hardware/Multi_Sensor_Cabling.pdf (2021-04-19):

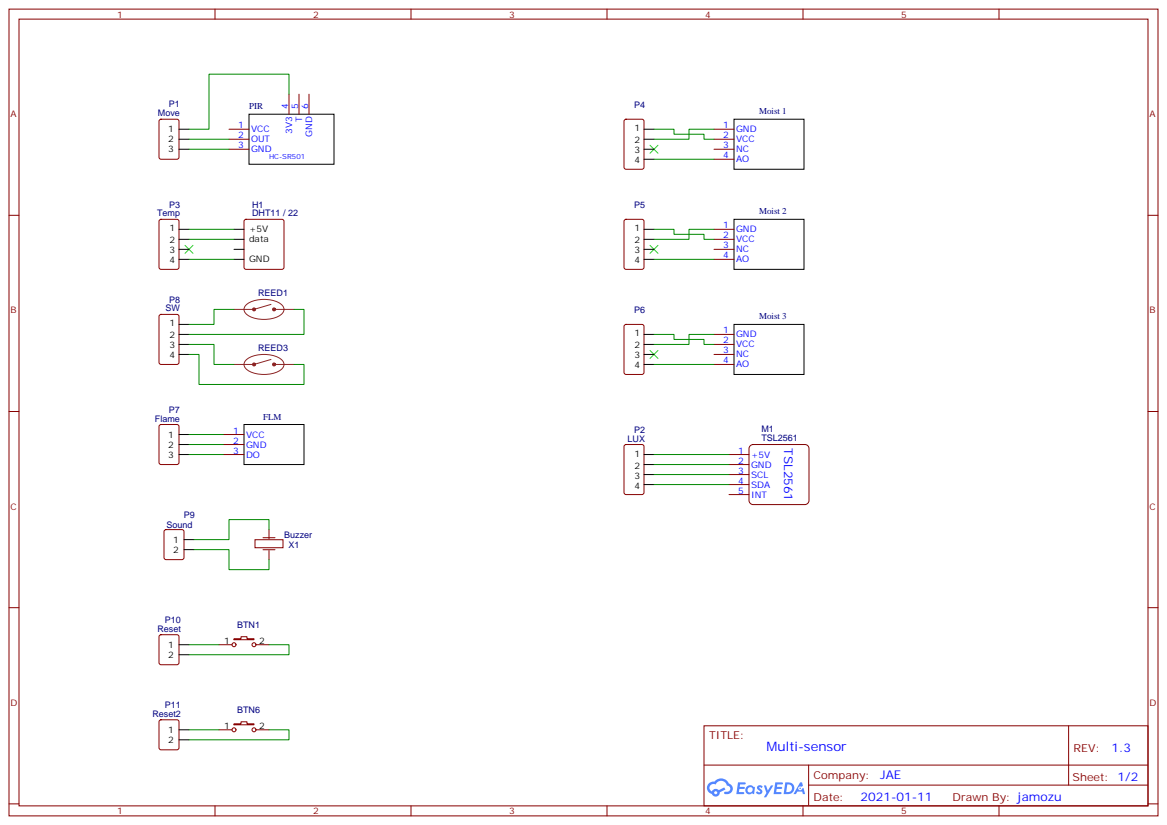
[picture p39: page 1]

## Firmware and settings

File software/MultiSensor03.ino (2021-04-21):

/**
 * The MySensors Arduino library handles the wireless radio link and protocol
 * between your home built sensors/actuators and HA controller of choice.
 * The sensors forms a self healing radio network with optional repeaters. Each
 * repeater and gateway builds a routing tables in EEPROM which keeps track of the
 * network topology allowing messages to be routed to nodes.
 *
 * Created by Henrik Ekblad <henrik.ekblad@mysensors.org>
 * Copyright (C) 2013-2015 Sensnology AB
 * Full contributor list: https://github.com/mysensors/Arduino/graphs/contributors
 *
 * Documentation: http://www.mysensors.org
 * Support Forum: http://forum.mysensors.org
 *
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
 *
 * ===============================================================================================
 * This software may be modified and distributed under the terms of the MIT license.
 *
 * LICENSE
 * <https://mit-license.org/>.
 * ------------------------------------------------------------------------------------------------
 * Copyright © 2020 Jesus Amozurrutia
 * 
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
 * ===============================================================================================
 * MULTI-SENSOR
 * 
 * This project consists of a module that manages different sensors for home use. The idea is to 
 * be able to mix and match different sensors, according to the requirements of each area of the 
 * house, using a single PCB design and a configurable sketch, making it easier to setup and 
 * maintain a sensor network.
 * 
 * ===============================================================================================
 * CONFIGURATION
 * 
 * This software is prepared to operate on the Arduino (R) platform.
 * Make sure you have the required libraries installed:
 * - MySensors (https://www.mysensors.org/)
 * - DHT (https://github.com/adafruit/DHT-sensor-library)
 * - Adafruit sensors (https://github.com/adafruit/Adafruit_Sensor)
 * - TSL2561 (https://github.com/adafruit/Adafruit_TSL2561)
 * - BH1750 (https://github.com/Starmbi/hp_BH1750)
 *
 * The sketch settings are self explanatory. Go to the "Configuration starts here" section at the 
 * beginning of the sketch and define the properties of the pre-processor according to the sensors 
 * present in the module.
 * The sensors are defined first and then the measurements to be made. In the event of 
 * inconsistencies, compilation errors may occur. It is convenient to compile with warnings 
 * activated, in which case inconsistencies in the configuration will be reported.
 *
 * ===============================================================================================
 *
 * EEPROM
 * 
 * 0   - 9  -> Reserved positions
 * 10  - 20 -> Battery calibration
 * 30+      -> Air quality sensors
 * 
 * ===============================================================================================
 *
 * CAVEATS
 * 
 * Button
 * ------
 *   The module uses 1 of 3 pins for the "Reset/Test/Calibrate" button. 
 *   
 *   Pin D2 or D3 are normally assigned to the button, depending on the sensors configured.
 *   If both D2 or D3 are required for sensors, D1 can be used, but sleep should be disabled to 
 *   allow consant monitoring of the status of the button.
 *   
 *   D1 is required for serial communication in debug mode (MY_DEBUG or MOD_DEBUG). To still be 
 *   able to debug the module D6 is used instead, but the MQ-7 sensor is then not enabled.
 *   
 *   It is possible to use some other pin of one of the sensors that is not in use, in order to 
 *   debug the CO sensor and the button at the same time, but you must modify the wiring and the 
 *   sketch accordingly.
 * 
 * Motion and Door/Window sensor
 * -----------------------------
 *   The Arduino Pro Mini has 2 pins that can trigger interruptions and wake up the module, 
 *   especially if it is battery operated. For this reason there can only be a combination of:
 *   - Moition Sensor + Door Sensor (1)
 *   - Door Sensor (1) + Door Sensor (2)
 * 
 *  Door sensor 3 can not wake up the module from sleep, therefore it will only report status 
 *  every SLEEP_TIME ms, and will not catch state changes in real time, unless sleep is disabled.
 *  
 * Air Quality Sensors
 * -----------------------------
 * The MQ series of air quality sensors requiere 5.0VCC, therefore is this sensors are used, a
 * 5V Arduino must be used.
 * 
 * CO Sensor
 * -----------------------------
 *   The Carbon monoxide sensor (MQ-7) has a duty cycle that requires alternating between two 
 *   voltage levels and constant monitoring, therefore the microprocessor will not enter sleep
 *   mode. To use this sensor it is recommended have the module connected to the mains and use 
 *   batteries only as backup.
 *   
 * ===============================================================================================
 * Flashing
 * ===============================================================================================
 * Board: "Arduino Pro or Pro Mini"
 * Procesor: Atmega328P (3.3V, 8MHz)
 * 
 * ===============================================================================================
 * 
  @author Jesus Amozurrutia Elizalde
  @version 0.8.3
  @date 2021/04/10
  Created on: Friday March 12 2020, 11:10:00
  Contact: jamozu@gmail.com
  Device: Arduino Pro Mini 3.3V or Arduino Pro Mini 5.0V
 * 
 */


//////////////////////////////////////////////////////////////////////////////////////////////////
//////////////////////////////////////////////////////////////////////////////////////////////////
// Configuration starts here
//              v            v            v            v            v            v            v 

// Module name broadcasted to HomeAssistant
#define MODULE_NAME "MultisensorE902"
// Software version
#define MODULE_VER "0.8.3"
// Debug messages to serial monitor for this sketch
#define MOD_DEBUG

//////////////////////////////////////////////////////////////////////////////////////////////////
// Define MySensors Library parameters
//////////////////////////////////////////////////////////////////////////////////////////////////
// Enable debug messages to serial monitor for My Sensors library.
//#define MY_DEBUG
// Enable and select radio type attached.
#define MY_RADIO_RF24
// Enable non blocking mode. Allows jumping to the loop() without waiting for radio registering.
#define MY_TRANSPORT_WAIT_READY_MS 2000
// Number of retrys for sensor presentation.
#define MY_PRESENTATION_RTR 5
// Number of retrys for messages.
#define MY_MESSAGE_RTR 5
// Enable repater functionality (disables sleep).
//#define MY_REPEATER_FEATURE

//////////////////////////////////////////////////////////////////////////////////////////////////
// Define Module Powering
//////////////////////////////////////////////////////////////////////////////////////////////////
// Arduino VCC 3.3 | 5.0
#define MOD_VCC 3.3
// Battery operated or battery backup
#define MOD_BATTERY
// Module has a power supply
//#define MOD_POWER

//////////////////////////////////////////////////////////////////////////////////////////////////
// Define Sensors
//////////////////////////////////////////////////////////////////////////////////////////////////
#define SENS_DOOR1        // Door/window sensor
//#define SENS_DOOR2      // Second door/window sensor (Same pin as SENS_MOTION)
#define SENS_DOOR3        // Third door/window sensor (No interruption)
#define SENS_MOTION       // Motion sensor (Same pin as SENS_DOOR2)
#define SENS_DHT          // DHT11/DHT22 Sensor (Temperature / humidity)
//#define SENS_LIGHT        // Light sensor (Same pin as SENS_LUX)
#define SENS_LUX          // Lux sensor (Same pin as SENS_LIGHT), Set the Meter type in the 
                          // "Measurements" section with the MOD_LUX parameter
#define SENS_FLAME        // Flame sensor
//#define SENS_MQ2          // MQ2 Air quality sensor (Smoke, LPG, Natural Gas, CO) 
//#define SENS_MQ5          // MQ5 Air quality sensor (LPG, Natural, CO)
//#define SENS_MQ7          // MQ7 Air quality sensor (CO)
#define SENS_MOIST1       // Moisture sensor 1 (Same pins as SENS_MQ7)
#define SENS_MOIST2       // Moisture sensor 2 (Same pins as SENS_MQ2)
#define SENS_MOIST3       // Moisture sensor 3 (Same pins as SENS_MQ5)

//////////////////////////////////////////////////////////////////////////////////////////////////
// Define Measurements
//////////////////////////////////////////////////////////////////////////////////////////////////
#define MOD_TEMPERATURE   // Temperature (Requires SENS_DHT)
#define MOD_HUMIDITY      // Humidity (Requires SENS_DHT)
//#define MOD_SMOKE         // Smoke measurement (requires SENS_MQ2)
//#define MOD_LPG           // LPG measurement (requires SENS_MQ2 and/or SENS_MQ5)
//#define MOD_GAS           // Natural Gas measurement (requires SENS_MQ2 and/or SENS_MQ5)
//#define MOD_CO            // Carbon Monoxide measurement (requires SENS_MQ2 and/or SENS_MQ7)
#define MOD_LEAK1         // Use SENS_MOIST1 as a leak sensor (Requires SENS_MOIST1).
#define MOD_LEAK2         // Use SENS_MOIST2 as a leak sensor (Requires SENS_MOIST2).
#define MOD_LEAK3         // Use SENS_MOIST3 as a leak sensor (Requires SENS_MOIST3).
//#define MOD_MQ7_FINE      // Turn On MQ-7 sensor only to get a fine read of CO levels, based
                            // on raw readings from SENS_MQ2. (Requires SENS_MQ2 and SENS_MQ7).
                            // This setting allows a longer battery life.
#define MOD_LUX TSL2561   // TSL2561, BH1750
                          // Requires the respective libraries:
                          // Adafruit TSL2561
                          // BH1750

//////////////////////////////////////////////////////////////////////////////////////////////////
// Alarm
//////////////////////////////////////////////////////////////////////////////////////////////////
#define MOD_ALARM         // Audible alarm, used by air quality, moisture and leak sensors 

//////////////////////////////////////////////////////////////////////////////////////////////////
// Parameters for the Module sleep / updates
//////////////////////////////////////////////////////////////////////////////////////////////////
// Sleep time between reports (in milliseconds).
static const uint32_t SLEEP_TIME = 60000;
// Minimum time to be awake.
static const uint32_t AWAKE_INTERVAL = 500; 
// Default time between updates.
static const uint32_t UPD_INTERVAL = 25000;
// Force sending an update after N sensor reads, so a controller showing the timestamp of the last 
// update doesn't show something like 3 hours in the case that the value does not change for a 
// while.
// i.e. the sensor would force sending an update every UPD_INTERVAL * UPD_N_READS [ms].
static const uint8_t UPD_N_READS = 5;
// Sleep cycles that force updates on all sensors.
static const uint8_t SLEEP_CYCLES = 5;

//////////////////////////////////////////////////////////////////////////////////////////////////
// Parameters for Temperature and Humidity sensor
//////////////////////////////////////////////////////////////////////////////////////////////////
// Sensor type
#define DHTTYPE DHT11 // [DHT11|DHT22|DHT21]
// Set this offset if the sensor has a permanent small offset to the real temperatures.
// In Celsius degrees (as measured by the device)
#define TMP_OFFSET 0

//////////////////////////////////////////////////////////////////////////////////////////////////
// Parameters for the ligh/lux sensors
//////////////////////////////////////////////////////////////////////////////////////////////////
// Voltage produced by the sensor with 100% light.
#define         LIGHT_MAX               0
// Voltage produced by the sensor with 0% light.
#define         LIGHT_MIN               MOD_VCC
// Max. LUX supported by the sensor.
//#define         LUX_MAX                 120000
// Min. LUX supported by the sensor.
//#define         LUX_MIN                 0

//////////////////////////////////////////////////////////////////////////////////////////////////
// Air quality sensing parameters
//////////////////////////////////////////////////////////////////////////////////////////////////
// Define how many samples you are going to take in the calibration phase.
#define         AQS_CAL_TIMES             (50)
// Define the time interval(in milliseconds) between each samples in the calibration phase.
#define         AQS_CAL_INTERVAL          (500)
// Define how many samples you are going to take in normal operation.
#define         AQS_READ_TIMES            (5)
// Define the time interval(in milliseconds) between each samples in normal operation.
#define         AQS_READ_INTERVAL         (50)
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
void loop() {
  ////////////////////////////////////////////////////////////////////////////////////////////////
  // Loop timer
  ////////////////////////////////////////////////////////////////////////////////////////////////
  unsigned long lTmr = millis();
  bool msst = false;
  if (msst) msst = false;
  if(ilTmr == 0) {
    ilTmr = lTmr;
  }
  
  ////////////////////////////////////////////////////////////////////////////////////////////////
  // Initial value
  ////////////////////////////////////////////////////////////////////////////////////////////////
  if (isPresented && !initialValueSent) {
    #ifdef MOD_DEBUG
      Serial.println(F("Sending initial values"));
    #endif
    #ifdef CHILD_ID_MOV
      msst = sendMsg(msgMov.set(0));
    #endif
    #ifdef CHILD_ID_DO1
      msst = sendMsg(msgDor.set(0));
    #endif
    #ifdef CHILD_ID_DO2
      msst = sendMsg(msgDo2.set(0));
    #endif
    #ifdef CHILD_ID_DO3
      msst = sendMsg(msgDo3.set(0));
    #endif
    #ifdef CHILD_ID_TMP
      msst = sendMsg(msgTmp.set(22));
    #endif
    #ifdef CHILD_ID_HUM
      msst = sendMsg(msgHum.set(0));
    #endif
    #ifdef CHILD_ID_LGT
      msst = sendMsg(msgLgt.set(0));
    #endif
    #ifdef CHILD_ID_LUX
      msst = sendMsg(msgLux.set(0));
    #endif
    #ifdef CHILD_ID_FLM
      msst = sendMsg(msgFlm.set(0));
    #endif
    #ifdef CHILD_ID_SMK
      msst = sendMsg(msgSmk.set(0));
    #endif
    #ifdef CHILD_ID_LPG
      msst = sendMsg(msgLpg.set(0));
    #endif
    #ifdef CHILD_ID_GAS
      msst = sendMsg(msgGas.set(0));
    #endif
    #ifdef CHILD_ID_COS
      msst = sendMsg(msgCos.set(0));
    #endif
    #ifdef CHILD_ID_MS1
      msst = sendMsg(msgMs1.set(0));
    #endif
    #ifdef CHILD_ID_MS2
      msst = sendMsg(msgMs2.set(0));
    #endif
    #ifdef CHILD_ID_MS3
      msst = sendMsg(msgMs3.set(0));
    #endif
    #ifdef CHILD_ID_LK1
      msst = sendMsg(msgLk1.set(0));
    #endif
    #ifdef CHILD_ID_LK2
      msst = sendMsg(msgLk2.set(0));
    #endif
    #ifdef CHILD_ID_LK3
      msst = sendMsg(msgLk3.set(0));
    #endif
    #ifdef CHILD_ID_ALM
      msst = sendMsg(msgAlm.set(0));
    #endif
    #ifdef CHILD_ID_BAT
      msst = sendMsg(msgBat.set(0.0, 2));
    #endif
    // Flag
    initialValueSent = true;
    //Serial.println(F("Requesting initial value from controller"));
    //request(CHILD_ID, V_STATUS);
    //wait(2000, C_SET, V_STATUS);
  }
  
  ////////////////////////////////////////////////////////////////////////////////////////////////
  // Motion sensor
  ////////////////////////////////////////////////////////////////////////////////////////////////
  #ifdef SENS_MOTION
    bool vMove = digitalRead(PIN_MOVE) == HIGH;
    if (vMove != movLast || sleepCycles >= SLEEP_CYCLES) {
      // Send the motion value
      if (sendMsg(msgMov.set(vMove ? "1" : "0"))) {
        movLast = vMove;
      }
      //if (vMove == LOW) {
      //  noBat = true;
      //}
      #ifdef MOD_DEBUG
        Serial.print(F("Motion: "));
        Serial.println(vMove);
      #endif
    }
  #endif
  
  ////////////////////////////////////////////////////////////////////////////////////////////////
  // Door 1 sensor
  ////////////////////////////////////////////////////////////////////////////////////////////////
  #ifdef SENS_DOOR1
    door1.update();
    int vDoor = door1.read();
    if (vDoor != dor1Last || sleepCycles >= SLEEP_CYCLES) {
      // Send the door value
      if (sendMsg(msgDor.set(vDoor == HIGH ? "1" : "0"))) {
        dor1Last = vDoor;
      }
      #ifdef MOD_DEBUG
        Serial.print(F("Door 1: "));
        Serial.println(vDoor);
      #endif
    }
  #endif
  
  ////////////////////////////////////////////////////////////////////////////////////////////////
  // Door 2 sensor
  ////////////////////////////////////////////////////////////////////////////////////////////////
  #ifdef SENS_DOOR2
    door2.update();
    int vDoor2 = door2.read();
    if (vDoor2 != dor2Last || sleepCycles >= SLEEP_CYCLES) {
      // Send the door value
      if (sendMsg(msgDo2.set(vDoor2 == HIGH ? "1" : "0"))) {
        dor2Last = vDoor2;
      }
      #ifdef MOD_DEBUG
        Serial.print(F("Door 2: "));
        Serial.println(vDoor2);
      #endif
    }
  #endif
  
  ////////////////////////////////////////////////////////////////////////////////////////////////
  // Door 3 sensor
  ////////////////////////////////////////////////////////////////////////////////////////////////
  #ifdef SENS_DOOR3
    door3.update();
    int vDoor3 = door3.read();
    if (vDoor3 != dor3Last || sleepCycles >= SLEEP_CYCLES) {
      // Send the door value
      if (sendMsg(msgDo3.set(vDoor3 == HIGH ? "1" : "0"))) {
        dor3Last = vDoor3;
      }
      #ifdef MOD_DEBUG
        Serial.print(F("Door 3: "));
        Serial.println(vDoor3);
      #endif
    }
  #endif
  
  ////////////////////////////////////////////////////////////////////////////////////////////////
  // Temperature and Humidity sensor
  ////////////////////////////////////////////////////////////////////////////////////////////////
  #ifdef SENS_DHT
    //////////////////////////////////////////////////////////////////////////////////////////////
    // Temp. Sensor
    //////////////////////////////////////////////////////////////////////////////////////////////
    if(dhtTimer > UPD_INTERVAL_DHT) {
      dhtTimer = 0;
      // Force reading sensor, so it works also after sleep()
      dht.read(true);
      #ifdef MOD_TEMPERATURE
        // Get temperature from DHT library
        float vTemperature = dht.readTemperature();
        if (isnan(vTemperature)) {
          #ifdef MOD_DEBUG
            Serial.println(F("Failed reading temperature from DHT!"));
          #endif
          delay(10);
        } else if (vTemperature != tmpLast || tmpUpdate >= UPD_N_READS) {
          // Only send temperature if it changed since the last measurement or if we didn't send an update for N times
          // Apply the offset before converting
          vTemperature += TMP_OFFSET;
          if (!isMetric) {
            vTemperature = dht.convertCtoF(vTemperature);
          }
          if (sendMsg(msgTmp.set(vTemperature, 1))) {
            tmpLast = vTemperature;
          }
          #ifdef MOD_DEBUG
            Serial.print(F("Temperature: "));
            Serial.println(vTemperature);
          #endif
          // Reset no updates counter
          tmpUpdate = 0;
        } else {
          // Increase no update counter if the temperature did not changed
          tmpUpdate++;
        }
      #endif
      
      ////////////////////////////////////////////////////////////////////////////////////////////
      // Humidity Sensor
      ////////////////////////////////////////////////////////////////////////////////////////////
      #ifdef MOD_HUMIDITY
        // Get humidity from DHT library
        float vHumidity = dht.readHumidity();
        if (isnan(vHumidity)) {
          #ifdef MOD_DEBUG
            Serial.println(F("Failed reading humidity from DHT"));
          #endif
          delay(10);
        } else if (vHumidity != humLast || humUpdate >= UPD_N_READS) {
          // Only send humidity if it changed since the last measurement or if we didn't send an update for n times
          if (sendMsg(msgHum.set(vHumidity, 1))) {
            humLast = vHumidity;
          }
          #ifdef MOD_DEBUG
            Serial.print(F("Humidity: "));
            Serial.println(vHumidity);
          #endif
          // Reset no updates counter
          humUpdate = 0;
        } else {
          // Increase no update counter if the humidity did not changed
          humUpdate++;
        }
      #endif
    }
  #endif
  
  ////////////////////////////////////////////////////////////////////////////////////////////////
  // Light sensor
  ////////////////////////////////////////////////////////////////////////////////////////////////
  #ifdef SENS_LIGHT
    //LIGHT_MAX
    if(lgtTimer > UPD_INTERVAL_LGT) {
      lgtTimer = 0;
      // Read light sensor in %
      int16_t vLight = (((readRaw(PIN_LGT) / 1023 * MOD_VCC) - LIGHT_MIN) / (LIGHT_MAX - LIGHT_MIN)) * 100;
      if (vLight < 0) {
        vLight = 0;
      } else if (vLight > 100) {
        vLight = 100;
      }
      // Update value
      if (vLight != lgtLast || lgtUpdate >= UPD_N_READS) {
        if (sendMsg(msgLgt.set(vLight))) {
          lgtLast = vLight;
        }
        #ifdef MOD_DEBUG
          Serial.print(F("Light level: "));
          Serial.println(vLight);
        #endif
        // Reset no updates counter
        lgtUpdate = 0;
      } else {
        lgtUpdate++;
      }
    }
  #endif
  
  ////////////////////////////////////////////////////////////////////////////////////////////////
  // LUX sensor
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

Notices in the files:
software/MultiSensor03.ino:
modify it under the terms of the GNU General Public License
